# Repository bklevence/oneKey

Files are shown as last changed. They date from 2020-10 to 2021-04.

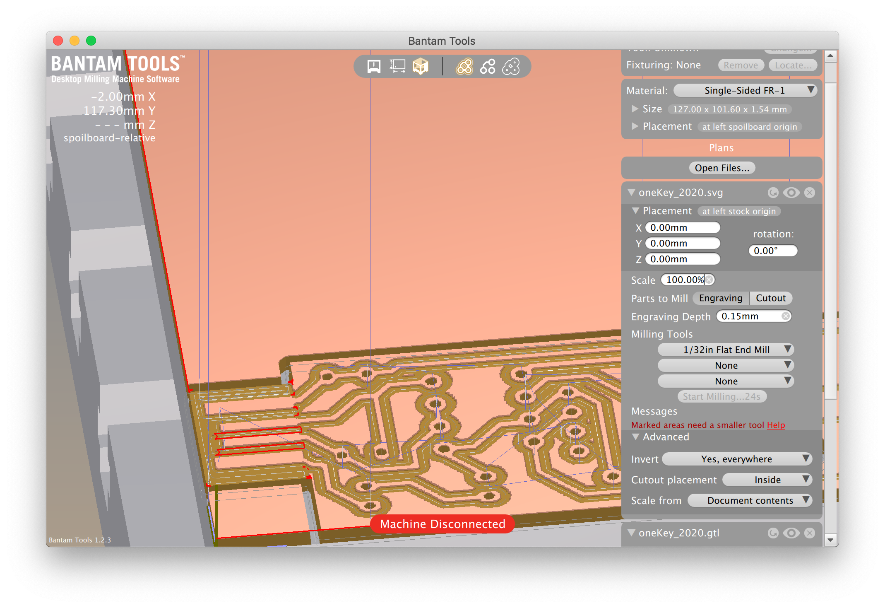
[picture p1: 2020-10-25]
Hardware/OneKey 2020/oneKey 2020/setup images/Screen Shot 2020-10-21 at 8.44.46 AM.png

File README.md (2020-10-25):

oneKey 2020
===========

jawnWare_8

Project Focus
-------------------
Developing a low-cost (<$2) and accessible derivative of the MaKey MaKey so that it can be sustainably deployed via workshops at various library branches.

The aim is to introduce youth in underserved/low-income communities to making hardware that they can then tinker/play/make with. It's adressing the question "Can I take this home?" and the inability for youth to use take projects using digital media tools such as the MaKey MaKey home.

In participating in this process we hope for them to take more ownership of their tools. We're also trying to adress wether or not the library and its participants can make their own tools for learning via desktop manufacturing and production methods.

So what is a MaKey MaKey?
-------------------
From Sparkfun's [*MaKey MaKey Documentation*](https://github.com/sparkfun/makeymakey):

*"Using the MaKey MaKey you can make anything into a key (get it?) just by connecting a few alligator clips. The MaKey MaKey is an invention kit that tricks your computer into thinking that almost anything is a keyboard. This allows you to hook up all kinds of fun things as an input."*

**How does it work?**

*"The MaKey MaKey uses high resistance switching to detect when you've made a connection even through materials that aren't very conductive (like leaves, pasta or people). This technique attracts noise on the input, so a moving window averager is used to lowpass the noise. The on-board ATMega32u4 communicates with your computer using the Human Interface Device (HID) protocol which means that it can act like a keyboard or mouse."*

Methods
-------------------
The original oneKey uses a vinyl cutter and 3M copper tape to make a low-barrier and low-cost method for creating traces to solder onto. If working indoors take precautions with ventilalation etc. Working currently on a PCB kit version.

Need for the oneKey
-------------------
* 3M Copper Tape (used to be much cheaper, working on a thinner tape iteration.) ([Buy](http://www.amazon.com/inch-yds-Copper-Foil-Tape/dp/B00CBPM9RY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) | [HowTo](http://www.kobakant.at/DIY/?p=1132))
* Attiny85 ([Buy](http://www.digikey.com/product-detail/en/0/ATTINY85-20PU-ND) | [HowTo](about:blank))
* Attiny85 Standoff/ IC DIP Socket([Buy](http://www.digikey.com/product-detail/en/0/ATTINY85-20PU-ND) | [HowTo](about:blank))
* Resistors: 2x [68 ohm](http://www.digikey.com/product-detail/en/0/S68HCT-ND) , 1x [1.5K](http://www.digikey.com/product-detail/en/0/S1.5KHCT-ND), 1x [1M ohm](http://www.digikey.com/product-detail/en/0/CF14JT1M00CT-ND).
* Zener Diode ([Buy](http://www.digikey.com/product-detail/en/0/1N4148DICT-ND) | [HowTo](about:blank))
* USB Cable ([Buy](http://www.amazon.com/Eversame-Colorful-Hi-Speed-Universal-Phones-Black/dp/B00OC6WR22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) | [HowTo](about:blank))
* Vinyl Cutter (All makes/models work) ([Buy](http://www.amazon.com/Vinyl-Cutter-USCutter-34in-BUNDLE/dp/B00CDQGCTW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) | [HowTo](about:blank))
* Soldering Iron ([Buy](about:blank) | [HowTo](about:blank))
* Needle Nose Pliers ([Buy](about:blank) | [HowTo](about:blank))
* Wire Cutter ([Buy](about:blank) | [HowTo](about:blank))
* Wire Stripper ([Buy](about:blank) | [HowTo](about:blank))
* Tiny AVR Programmer or Equivalent ([Buy](https://www.sparkfun.com/products/11801) | [HowTo](https://learn.sparkfun.com/tutorials/tiny-avr-programmer-hookup-guide/))

Repository Contents
-------------------
* **/Firmware** - Arduino Files+
* **/Hardware** - All design files (EAGLE, FRITIZING, AI+)
* **/Instructon** - Instructors materials
* **/Supplies** - Previous part orders

Variations
----------------
**Vinyl Cut Copper Tape**

oneKey Vinyl

This build requres soldering and takes an hour to construct. The tape can be tricky to adhere to a substrate, but for all intents and purposes IT WORKS!

Requires the installation of the Digispark Arduino IDE to upload and run code from /Firmware.
All vector files needed for vinylcutting reside in /Hardware.

**PCB(REV.1)**  

PCB

PCB2

Looking to make a PCB kit, currently waiting for PCB to be milled. See the Eagle Schematics and Board files in /Hardware.

**Quick-build(Still in Development)**  
This build is solderless, can be built in less than an hour.

Links/Sources
-------------------
* [Digispark](http://digistump.com/products/1)
* [Digispark IDE](about:blank)
* [Digispark Clone](about:blank)
* [BhavyaShukla - Makey-makey-using-arduino-uno-r3-Multiple-input](https://github.com/BhavyaShukla/Makey-makey-using-arduino-uno-r3-Multiple-inputs-)
* [Moving Avarage Library](https://github.com/BhavyaShukla/Makey-makey-using-arduino-uno-r3-Multiple-inputs-)
* [JoyLab's/Sparkfun's - MaKey MaKey](https://github.com/sparkfun/makeymakey)
* [avrdude tutorials](https://learn.adafruit.com/usbtinyisp/avrdude)

toDo
-------------------
* easier peeling
* solderless
* remove usb cable
* ~~thruhole prototype~~
* non-digispark
* attiny45?
* find other hardware thruhole prototype
* do outreach, find other ppl who want this

brief history
-------------------
To date two iterations of the one input MaKey MaKey derivative, "MaKey MaKey MaKey", or officially "oneKey" for short, have been deployed. The first generation proved that youth could make, hack, and play with their own hardware. After various form and material explorations as well as a circuit redesign it is currently in its second phase. The new design is easier to handle, the cost per unit has dropped from $7 to $1.30, it's quicker to make, and there is still much more to refine.

people
-------------------
* bk brandonklevence@gmail.com
* the Maker Jawn Initiative info@makerjawn.org

License Information
-------------------
The hardware is released under [Creative Commons Share-alike 3.0](http://creativecommons.org/licenses/by-sa/3.0/).  
All other code is open source hardware so please feel free to do anything you want with it;
you buy me a beer if you use this and we meet someday ([Beerware license](http://en.wikipedia.org/wiki/Beerware)).
Please support [Digispark](https://github.com/sparkfun/makeymakey) and [JoyLabs](https://github.com/sparkfun/makeymakey) and buy their products if you decide to remix. Without their creativity and ingenuity this project would never have happened.

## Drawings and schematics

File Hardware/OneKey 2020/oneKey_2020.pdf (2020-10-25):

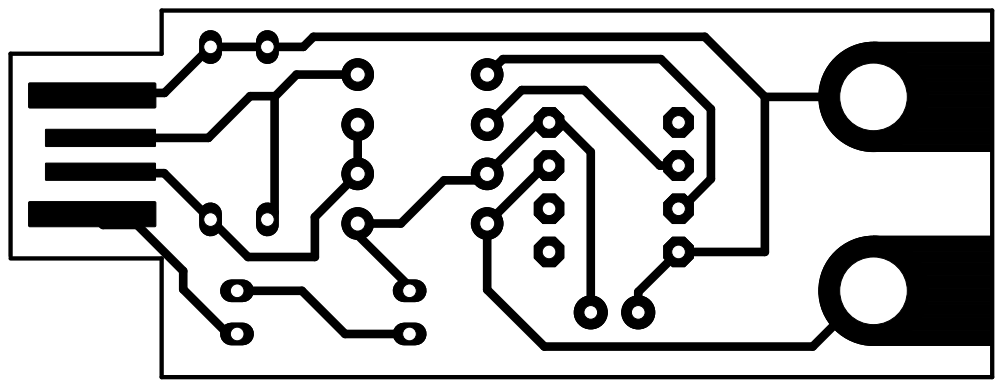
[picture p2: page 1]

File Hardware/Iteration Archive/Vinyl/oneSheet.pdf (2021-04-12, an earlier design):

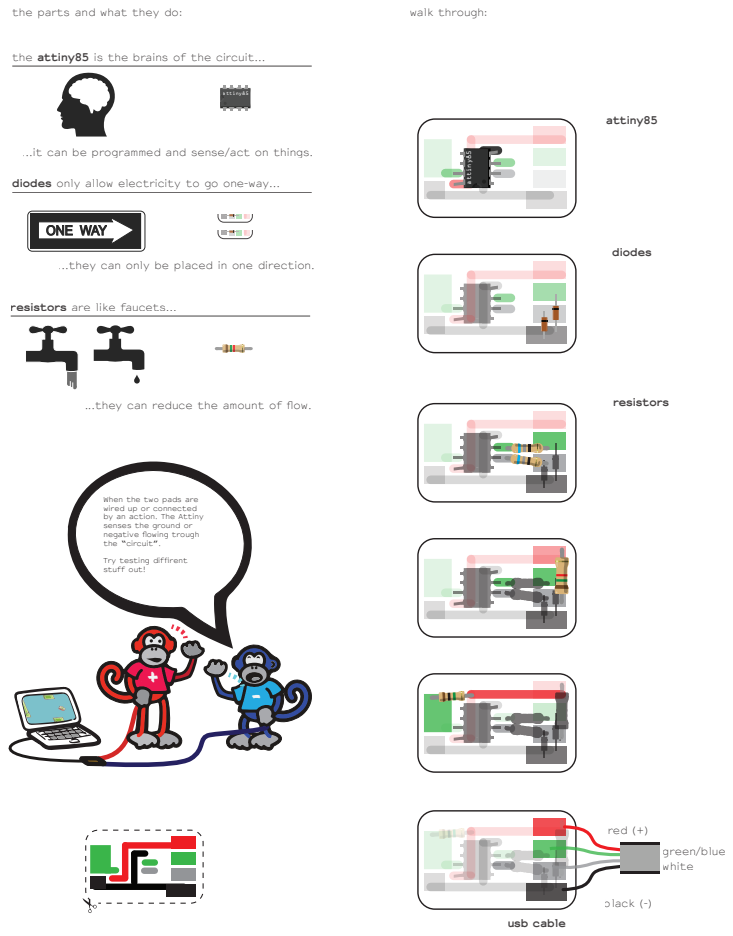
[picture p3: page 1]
ONE WAY; the parts and what they do:; walk through:; attiny85; attiny85 attiny85 attiny85 attiny85 attiny85; diodes; resistors; usb cable; black (-); red (+); green/blue white

the attiny85 is the brains of the circuit...

...it can be programmed and sense/act on things.

diodes only allow electricity to go one-way...

...they can only be placed in one direction.

resistors are like faucets...

...they can reduce the amount of flow.

When the two pads are
wired up or connected
by an action. The Attiny
senses the ground or
neJatLYe flowLnJ trouJh
the “circuit”.
7ry teVtLnJ dLfrent
stuff out!

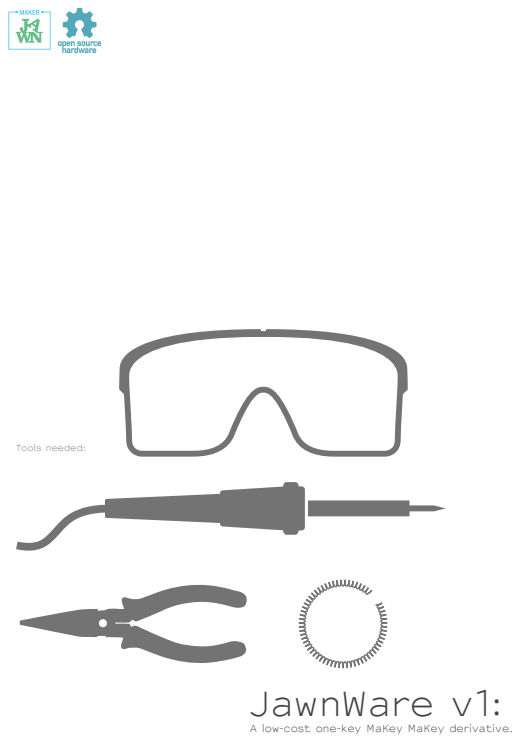
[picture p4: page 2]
JawnWare v1:; Tools needed:

A low-cost one-key MaKey MaKey derivative.

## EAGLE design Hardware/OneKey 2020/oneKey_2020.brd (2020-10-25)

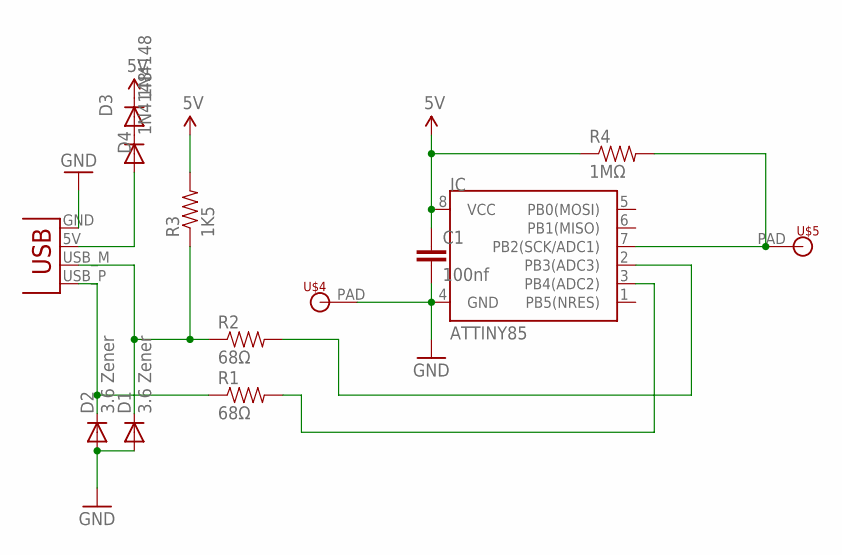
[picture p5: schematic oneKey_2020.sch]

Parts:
C1: 100nf; CAP-PTH-SMALL-KIT
D1, D2: 3.6 Zener; DO35-10
D3, D4: 1N4148; DO35-10
IC: ATTINY85; DIP08
R1, R2: 68Ω; AXIAL-0.3
R3: 1K5; AXIAL-0.3
R4: 1MΩ; AXIAL-0.3
U$4, U$5: MICROBIT_PAD
X1: USBPCB; USB-A-PCB

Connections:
5V: C1.1, D3.C, IC.8 (VCC), R3.P$2 (2), R4.P$1 (1)
GND: C1.2, D1.A, D2.A, IC.4 (GND), U$4.PAD, X1.GND
unnamed: IC.2 (PB3(ADC3)), R2.P$2 (2)
unnamed: IC.7 (PB2(SCK/ADC1)), R4.P$2 (2), U$5.PAD
unnamed: D3.A, D4.C
unnamed: D4.A, X1.5V (VBUS)
unnamed: IC.3 (PB4(ADC2)), R1.P$2 (2)
unnamed: D1.C, R2.P$1 (1), R3.P$1 (1), X1.USB_M (D-)
unnamed: D2.C, R1.P$1 (1), X1.USB_P (D+)

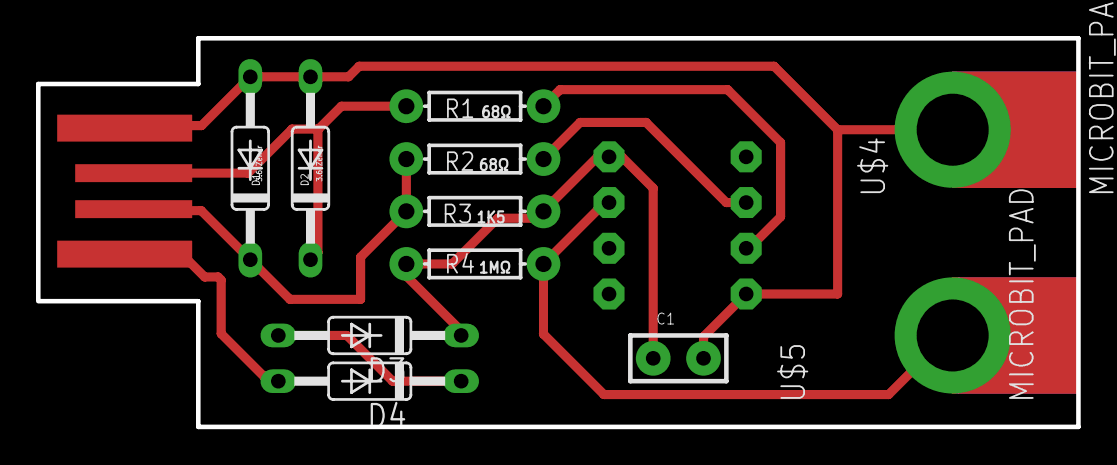
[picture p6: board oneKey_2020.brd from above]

Board: 2 copper layers, 57.8 x 21.6 mm, 13 parts (1 on the bottom side), 9 nets.

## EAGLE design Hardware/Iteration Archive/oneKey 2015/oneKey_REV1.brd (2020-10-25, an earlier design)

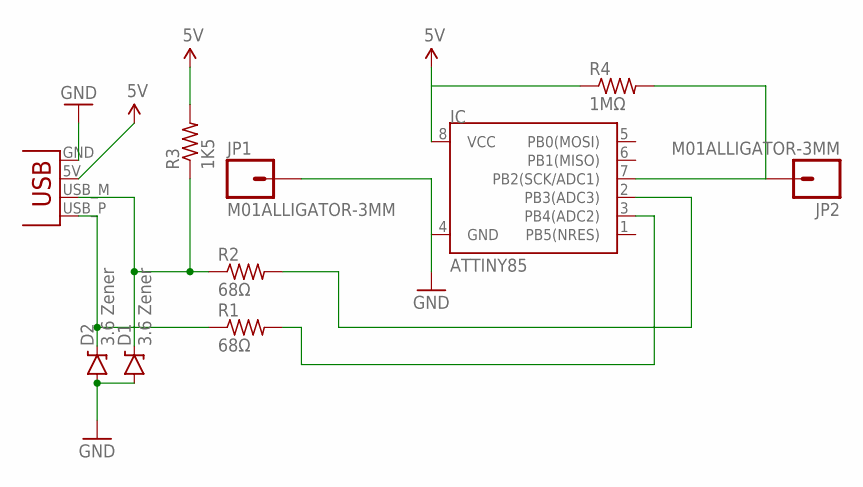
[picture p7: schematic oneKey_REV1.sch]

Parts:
D1, D2: 3.6 Zener; DIODE-ZENER
IC: ATTINY85; DIP08
JP1, JP2: M01ALLIGATOR-3MM; 1X01_ALLIGATOR_3MM
R1, R2: 68Ω; 0204/7
R3: 1K5; 0204/7
R4: 1MΩ; 0204/7
X1: USBPCB; USB-A-PCB

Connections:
5V: IC.8 (VCC), R3.2, R4.1, X1.5V (VBUS)
GND: D1.P$2 (A), D2.P$2 (A), IC.4 (GND), JP1.1@0, JP1.1@2, X1.GND
unnamed: IC.2 (PB3(ADC3)), R2.2
unnamed: IC.7 (PB2(SCK/ADC1)), JP2.1@0, JP2.1@2, R4.2
unnamed: IC.3 (PB4(ADC2)), R1.2
unnamed: D1.P$1 (C), R2.1, R3.1, X1.USB_M (D-)
unnamed: D2.P$1 (C), R1.1, X1.USB_P (D+)

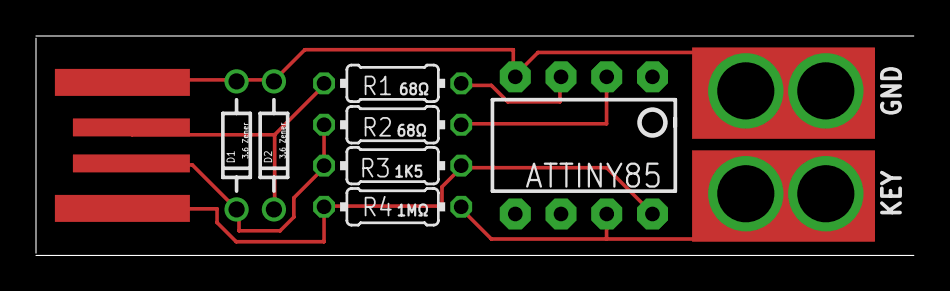
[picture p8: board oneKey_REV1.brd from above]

Board: 2 copper layers, 48.8 x 12.2 mm, 11 parts (1 on the bottom side), 7 nets.

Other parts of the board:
U$4: OSHW-LOGO-S

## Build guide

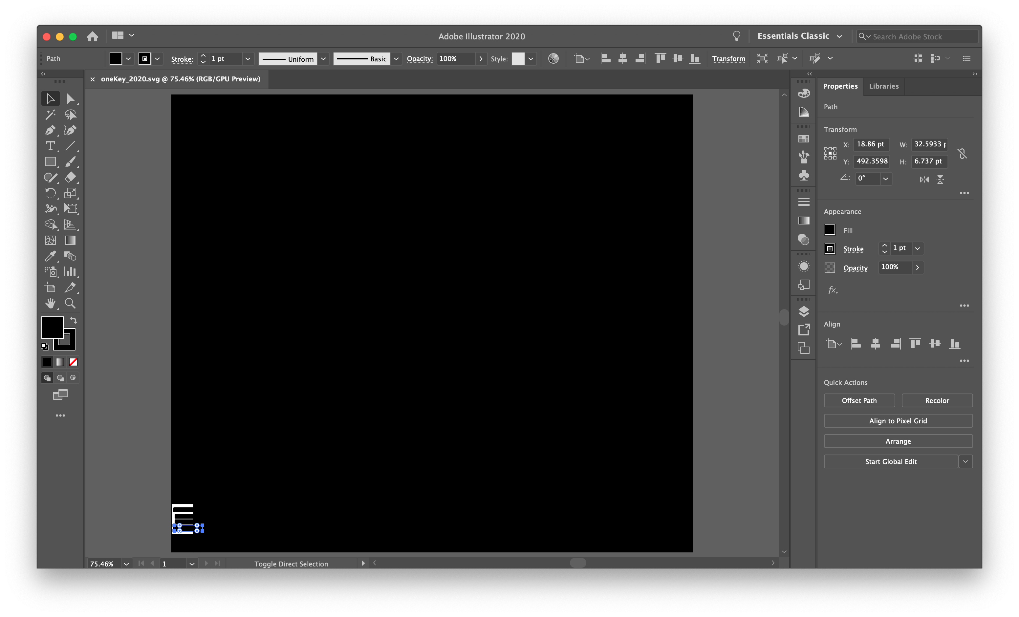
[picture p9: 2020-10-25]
Hardware/OneKey 2020/oneKey 2020/setup images/Screen Shot 2020-10-21 at 8.44.53 AM.png

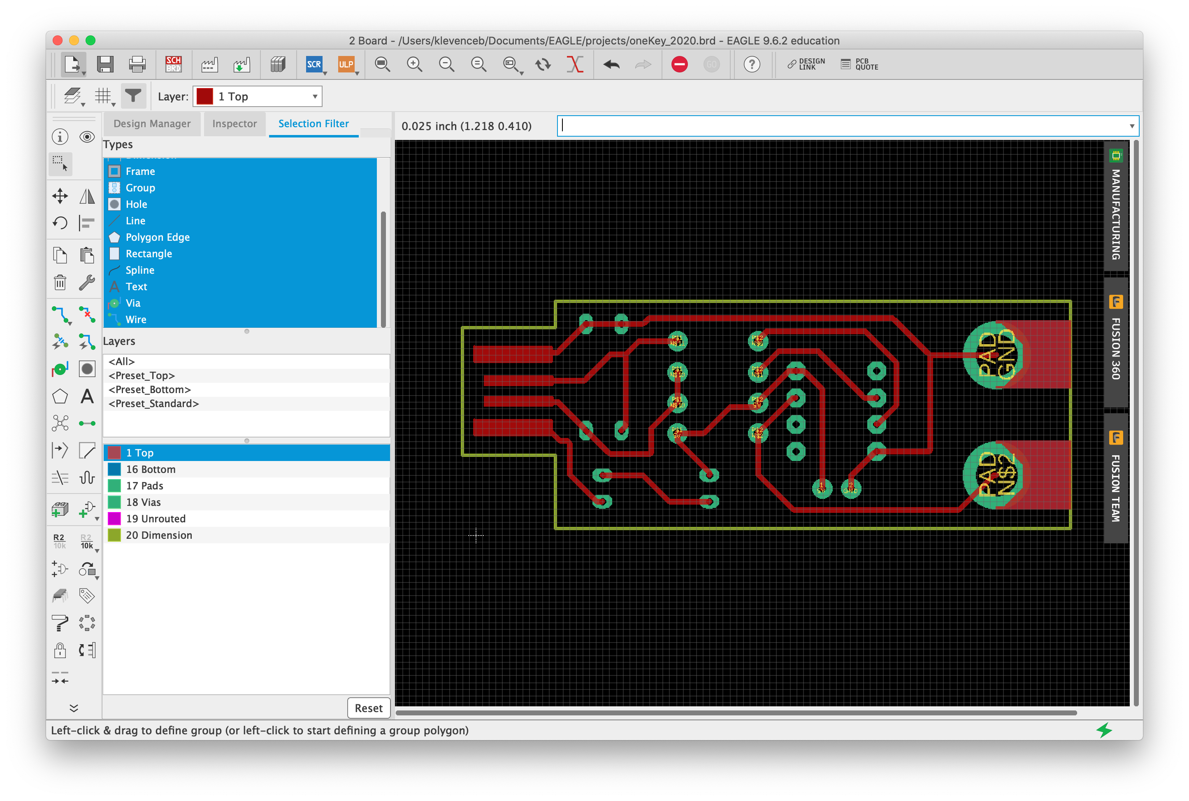
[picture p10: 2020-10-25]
Hardware/OneKey 2020/oneKey 2020/setup images/Screen Shot 2020-10-21 at 8.45.01 AM.png

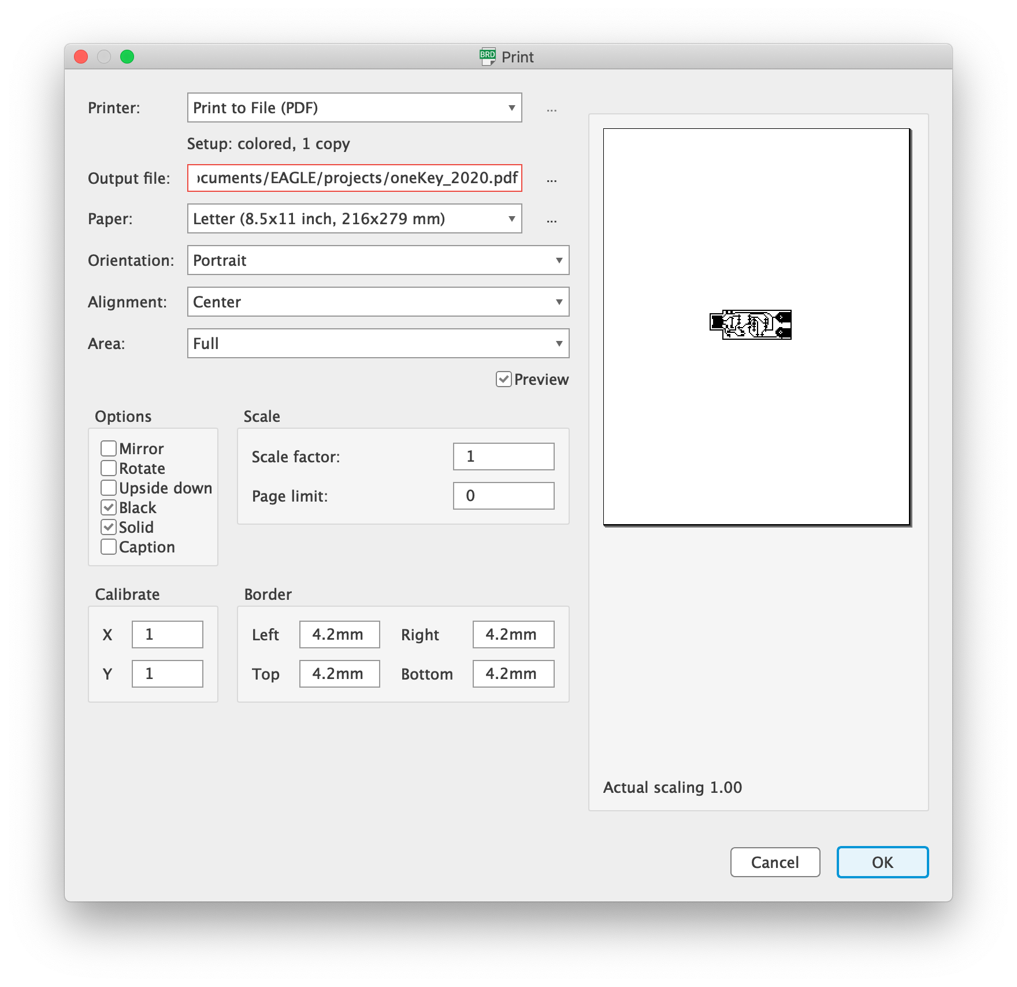
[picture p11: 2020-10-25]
Hardware/OneKey 2020/oneKey 2020/setup images/Screen Shot 2020-10-21 at 8.45.07 AM.png

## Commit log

2020-10-25 2020 Cleanup
    [incomplete.fzz, oneKey_REV1.brd, oneKey_REV1.sch]
2020-10-25 2020 Board for Bantam Mill
    Added two extra zenner for WIN7 compatibility. Layout for Bantam Mill in eagle. Microbit-lik aligator pads replace old sparkfun makey makey design.
    [incomplete.fzz, oneKey_2020.brd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]

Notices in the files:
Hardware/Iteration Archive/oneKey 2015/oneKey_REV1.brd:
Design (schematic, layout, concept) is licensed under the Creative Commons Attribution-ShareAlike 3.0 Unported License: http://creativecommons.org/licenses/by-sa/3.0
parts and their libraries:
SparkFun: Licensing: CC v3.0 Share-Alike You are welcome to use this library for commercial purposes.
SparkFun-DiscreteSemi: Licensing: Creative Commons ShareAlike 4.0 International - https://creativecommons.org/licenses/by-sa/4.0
